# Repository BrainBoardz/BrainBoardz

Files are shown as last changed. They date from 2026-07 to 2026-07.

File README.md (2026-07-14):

### 

## BRAINBOARDZ - PLUG and CODE! 

BZBOARDS

This is the official repository for the BrainBoardz BZBoard system. BZBoards are ESP32-S3 and RP2350B based video (DVI/VGA) and audio centric microcontroller computers. They support Arduino, CircuitPython, MicroPython, AnnexRDS and PlatformIO. Our mission is to empower designers to develop projects based on our advanced and powerful microcontroller architecture. The entire BrainBoardz system is fully documented abd open source. The PCB designs and schematics for all BrainBoardz hardware is released under the CERN-OHL-W V2 license. All software and firmware is released under the GNU GPLv3 License. 

Through the use of our expanding range of cross compatible modules and easy prototyping boards anyone can easily develop custom projects to harness the impressive capabilities of the Raspberry Pi RP2350B and the Espressif ESP32-S3. The boards are specifically designed to be easily adaptable to retro-PC projects. Simply connect one of our ESP32-S3 or RP235OB boards to a USB cable and you are ready to go. 

BZBOARDS

We do not permit 3rd party board developers to use our logo/branding (as per CERN-OHL-W V2), but you are welcome to indicate that your project is BrainBoardz compatible if it is 100% (pin) compatible and it is produced using lead free solder.  The PCB designs and schematics for all BrainBoardz hardware is released under the CERN-OHL-W V2 license. All software and firmware is released under the GNU GPLv3 License. 

***

Firmware Notes: 

The ESP32S3 Zushi board supports Arduino and AnnexRDS. The RP2350B Beanz board supports CircuitPython, Micropython, Arduino and PlaformIO. For further instructions on these platforms please visit the Downloads page of the BrainBoardz website at:

https://www.brainboardz.com/downloads/

Plug and Code! 

<!--
**BrainBoardz/BrainBoardz** is a ✨ _special_ ✨ repository because its `README.md` (this file) appears on your GitHub profile.

-->

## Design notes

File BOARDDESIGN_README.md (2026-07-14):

All BrainBoardz projects are developed in EasyEDA using the EasyEDA Standard Edition. You can download this editor from here: 

<https://easyeda.com/page/download>

The schematics use parts that are sourced primarilly from LCSC. As some components are added post board production please check the BOM carefully!!!

**To utilize the project in EasyEDA use File:**

1) Open and select the zip file. EasyEDA will import the json files. 
1) Simply make a project using these files and you are good to go. 
1) We recommend starting with the Nucleus as the base project. This will ensure compatibility with the mounting holes of the Neuron modules (Z and M). 

**Usage Notes:** 

You are welcome to design/manufacture your own BrainBoardz boards. We do not allow 3rd party boards and modules to use our logo/branding, but you are welcome to indicate “BrainBoardz Compatible” on your board if it is 100% compatible and it is manufactured using a lead free process.

Please ensure that you follow the design guidelines closely. The pin assignments are very specific and have to be 100% consistent to maintain module compatibility.  The distances between the dupont connectors must be very precise. 

The schematics for all BZBOARDS and BZMODS/BZCARDS are being released under the Creative Commons Attribution Share-Alike License Version 4.0.  All code and firmware for BrainBoardz boards are being released under the GPL V3 License.

` `If you design a really interesting BZBoard or BZModule we would love to see it!

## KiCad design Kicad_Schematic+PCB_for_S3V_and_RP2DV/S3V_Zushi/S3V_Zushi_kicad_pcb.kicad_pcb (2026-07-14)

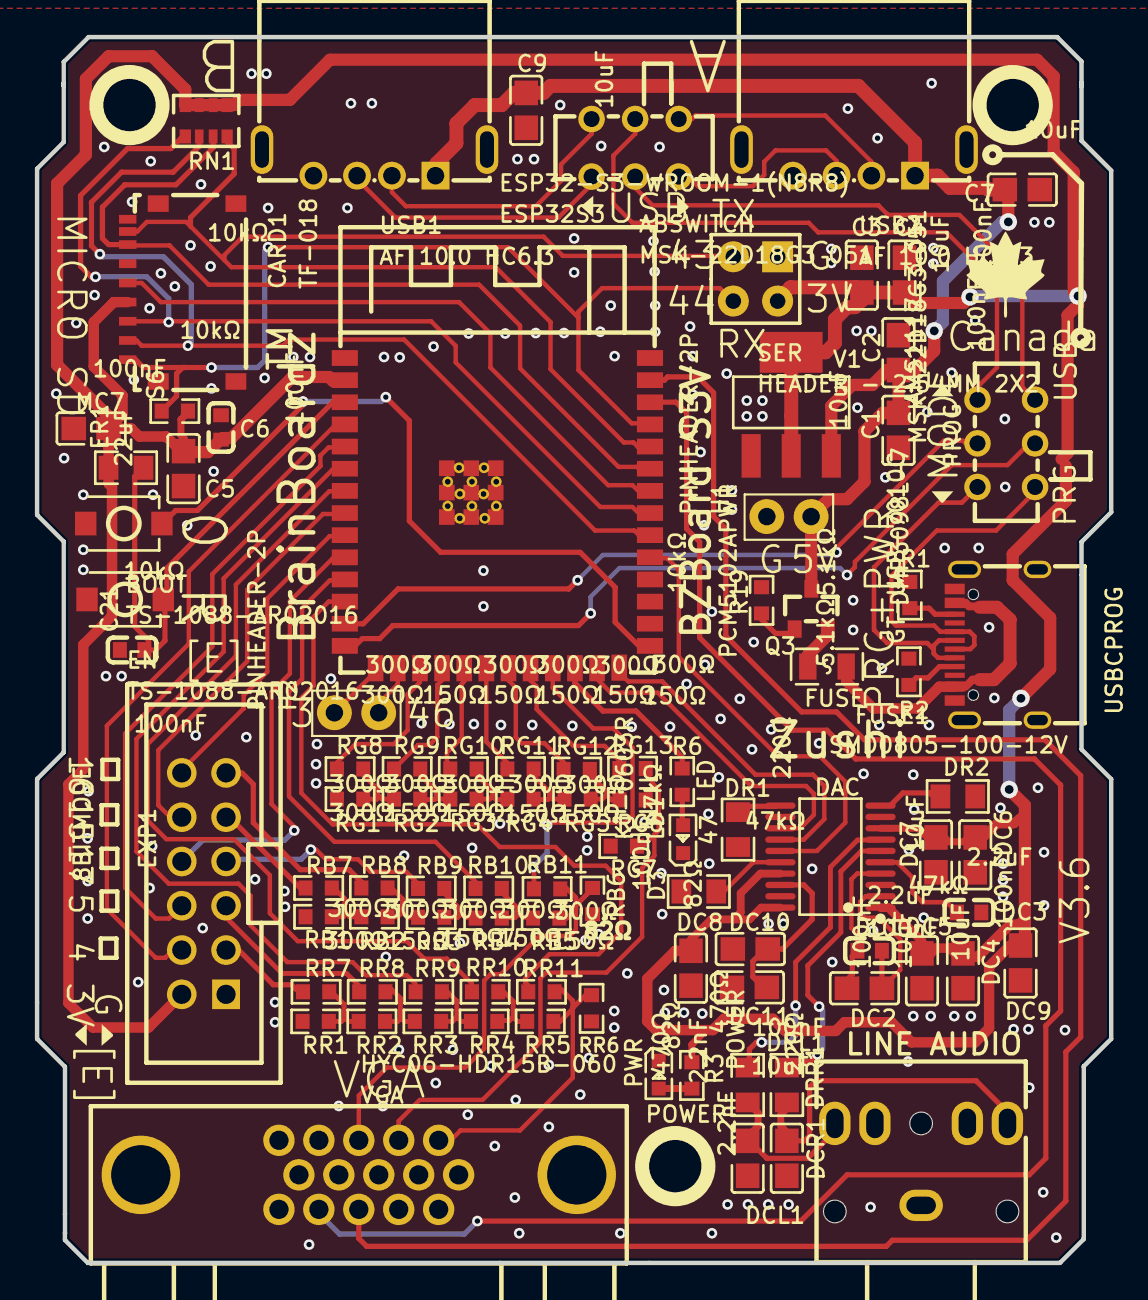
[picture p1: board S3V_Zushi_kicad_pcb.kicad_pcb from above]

Board: 2 copper layers, 61.6 x 70.3 mm, 107 parts (0 on the bottom side), 84 nets.

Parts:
ABSWITCH: MSK-22D18G3 051; SW-TH_HX-MSK-22D18G3-051
AUS: PJ-3062-G; AUDIO-TH_PJ-3062-G
BOOT: TS-1088-AR02016; SW-SMD_L3.9-W3.0-P4.45
C1, C3, C7, C9: 10uF; C0805
C2, C4: 100nF; C0805
C5: 22uF; C0805
C6, C21: 100nF; C0603
CARD1: TF-018; TF-SMD_TF-018
D3: 47kΩ; R0805
DAC: PCM5102APWR; TSSOP-20_L6.5-W4.4-P0.65-LS6.4-BL
DC1, DC3: 2.2uF; C0603
DC2, DC5, DC7, DC8, DC10: 100nF; C0805
DC4, DC6, DC9, DC11: 10uF; C0805
DCL1: 2.2nF; C0805
DCR1: 2.2nF; C0805
DR1, DR2: 47kΩ; R0805
DRL1: 470Ω; R0805
DRR1: 470Ω; R0805
EN: TS-1088-AR02016; SW-SMD_L3.9-W3.0-P4.45
ER1: 10kΩ; R0805
ESP32S3: ESP32-S3-WROOM-1(N8R8); WIRELM-SMD_ESP32-S3-WROOM-1
EXP1: 8BITMODE; IDC-TH_12P-P2.54_BOOMELE-2X6P-2.54MM
FUSE1: SMD0805-100-12V; F0805
H1, H2: PINHEADER-2P; CONNECTOR_PINHEADER_2.54MM{colon}PINHEADER_1X11_P_2.54MM
Hole_gge1593659: Hole_gge1593659
Hole_gge2213095: Hole_gge2213095
Hole_gge3207251: Hole_gge3207251
LD1: KT-0603R; LED0603-RD
MC7: 100nF; C0805
PROG: MSK-22D18G3 051; SW-TH_HX-MSK-22D18G3-051
PWR: POWER; LED0603-RD
Pad_gge1239083: Pad_gge1239083
Pad_gge1239086: Pad_gge1239086
Pad_gge1239089: Pad_gge1239089
Pad_gge1239092: Pad_gge1239092
Pad_gge1239095: Pad_gge1239095
Pad_gge1239098: Pad_gge1239098
Pad_gge1239101: Pad_gge1239101
Pad_gge1239104: Pad_gge1239104
Pad_gge1239107: Pad_gge1239107
Pad_gge1239110: Pad_gge1239110
Pad_gge1239113: Pad_gge1239113
Pad_gge1239116: Pad_gge1239116
Q3: DMP3098L-7; SOT-23_L2.9-W1.3-P1.90-LS2.4-BR
R1, R2: 5.1kΩ; R0603
R3, R6: 220Ω; R0603
R19: 10kΩ; R0603
RB1, RB7, RB8, RB9, RB10, RB11: 300Ω; R0603
RB2, RB3, RB4, RB5: 150Ω; R0603
RB6: 82Ω; R0603
RG1, RG8, RG9, RG10, RG11, RG12, RG13: 300Ω; R0603
RG2, RG3, RG4, RG5, RG6: 150Ω; R0603
RG7: 82Ω; R0603
RN1: 10kΩ; RES-ARRAY-SMD_0603-8P-L3.2-W1.6-BL
RR1, RR7, RR8, RR9, RR10, RR11: 300Ω; R0603
RR2, RR3, RR4, RR5: 150Ω; R0603
RR6: 82Ω; R0603
S6: 10kΩ; R0603
SER: HEADER - 2.54MM 2X2; 2X2X2.54MM HEADER
USB1, USB2: AF 10.0 HC6.3; USB-A-TH_AF-10.0-HC6.3
USBCPROG: GT-USB-7010C; USB-C-SMD_GT-USB-7010C
V1: AMS1117-3.3; SOT-223-3_L6.5-W3.4-P2.30-LS7.0-BR
VGA: HYC06-HDR15B-060; DSUB-TH_HYC06-HDR15B-060

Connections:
3.3V: C3.2, C4.2, C5.2, C6.2, CARD1.4, DAC.1, DAC.8, DAC.17, DAC.20, DC4.2, DC5.2, DC6.2, DC7.1, DC8.2, DC9.2, ER1.2, ESP32S3.2, EXP1.2, MC7.2, R3.1, RN1.1, RN1.2, RN1.3, RN1.4, S6.2, SER.3, V1.2, V1.4
+5V: C1.2, C2.2, C7.1, C9.1, H1.2, Q3.3, USB1.1, USB2.1, V1.3
AD+: ABSWITCH.1, USB2.3
AD-: ABSWITCH.4, USB2.2
BD+: ABSWITCH.3, USB1.3
BD-: ABSWITCH.6, USB1.2
BLUE: RB5.2, RB6.1, RB11.2, VGA.3
BOOT: BOOT.1, ESP32S3.27
D1+: PROG.4, USBCPROG.A6, USBCPROG.B6
D1-: PROG.1, USBCPROG.A7, USBCPROG.B7
D3_2: D3.2, DAC.16
DC2_1: DAC.4, DC1.1, DC2.1
DC2_2: DAC.2, DC1.2, DC2.2
DC3_1: DAC.5, DC3.1
DC10_1: DAC.18, DC10.1, DC11.1
DR1_2: DAC.11, DR1.2
DR2_2: DAC.10, DR2.2
EN: C21.1, EN.1, ER1.1, ESP32S3.3
G3: ESP32S3.15, H2.1
G4: ESP32S3.4, EXP1.4
G4VGA: EXP1.3, RR7.1
G5: ESP32S3.5, EXP1.6
G5VGA: EXP1.5, RR8.1
G6: ESP32S3.6, RR9.1
G7: ESP32S3.7, RR10.1
G8: ESP32S3.12, RR11.1
G9: ESP32S3.17, RG8.1
G10: ESP32S3.18, RG9.1
G11: ESP32S3.19, RG10.1
G12: ESP32S3.20, RG11.1
G13: ESP32S3.21, RG12.1
G14: ESP32S3.22, RG13.1
G15: ESP32S3.8, EXP1.10
G15VGA: EXP1.9, RB7.1
G16: ESP32S3.9, EXP1.12
G16VGA: EXP1.11, RB8.1
G17: ESP32S3.10, EXP1.8
G17VGA: EXP1.7, RB9.1
G18: ESP32S3.11, RB10.1
G19: ESP32S3.13, PROG.2
G20: ESP32S3.14, PROG.5
G21: ESP32S3.23, RB11.1
G38: DAC.15, ESP32S3.31
G39: CARD1.2, ESP32S3.32, RN1.6
G40: CARD1.3, ESP32S3.33, RN1.5
G41: CARD1.5, ESP32S3.34
G42: CARD1.7, ESP32S3.35, RN1.7
G43: CARD1.8, ESP32S3.36, RN1.8, SER.2
G44: CARD1.1, ESP32S3.37, S6.1, SER.4
G45: DAC.14, ESP32S3.26
G46: ESP32S3.16, H2.2
G47: ESP32S3.24, R6.1
G48: DAC.13, ESP32S3.25
GND: AUS.1, BOOT.2, C1.1, C2.1, C3.1, C4.1, C5.1, C6.1, C7.2, C9.2, C21.2, CARD1.6, CARD1.10, DAC.3, DAC.9, DAC.12, DAC.19, DC3.2, DC4.1, DC5.1, DC6.1, DC7.2, DC8.1, DC9.1, DC10.2, DC11.2, DCL1.1, DCR1.1, DR1.1, DR2.1, EN.2, ESP32S3.1, ESP32S3.40, ESP32S3.41, EXP1.1, H1.1, LD1.1, MC7.1, PWR.1, Pad_gge1239083.43, Pad_gge1239086.43, Pad_gge1239089.43, Pad_gge1239092.43, Pad_gge1239095.43, Pad_gge1239098.43, Pad_gge1239101.43, Pad_gge1239104.43, Pad_gge1239107.43, Pad_gge1239110.43, Pad_gge1239113.43, Pad_gge1239116.43, R1.2, R2.2, R19.2, RB1.1, RB6.2, RG1.1, RG7.2, RR1.1, RR6.2, SER.1, USB1.4, USB1.5, USB1.6, USB2.4, USB2.5, USB2.6, USBCPROG.1, USBCPROG.2, USBCPROG.3, USBCPROG.4, USBCPROG.A1B12, USBCPROG.B1A12, V1.1, VGA.5, VGA.6, VGA.7, VGA.8, VGA.10, VGA.16, VGA.17
GREEN: RG6.2, RG7.1, RG13.2, VGA.2
HSYNC: ESP32S3.39, VGA.13
OUTL: AUS.2, DCL1.2, DRL1.1
OUTLS: DAC.6, DRL1.2
OUTR: AUS.5, DCR1.2, DRR1.1
OUTRS: DAC.7, DRR1.2
Q3_1: Q3.1, R19.1
R3_2: PWR.2, R3.2
R6_2: LD1.2, R6.2
RB1_2: RB1.2, RB2.1, RB7.2
RB2_2: RB2.2, RB3.1, RB8.2
RB3_2: RB3.2, RB4.1, RB9.2
RB4_2: RB4.2, RB5.1, RB10.2
RED: RR5.2, RR6.1, RR11.2, VGA.1
RG1_2: RG1.2, RG2.1, RG8.2
RG2_2: RG2.2, RG3.1, RG9.2
RG3_2: RG3.2, RG4.1, RG10.2
RG4_2: RG4.2, RG5.1, RG11.2
RG5_2: RG5.2, RG6.1, RG12.2
RR1_2: RR1.2, RR2.1, RR7.2
RR8_2: RR2.2, RR3.1, RR8.2
RR9_2: RR3.2, RR4.1, RR9.2
RR10_2: RR4.2, RR5.1, RR10.2
UD+: ABSWITCH.2, PROG.6
UD-: ABSWITCH.5, PROG.3
USBCPROG_A5: R2.1, USBCPROG.A5
USBCPROG_B5: R1.1, USBCPROG.B5
VSYNC: ESP32S3.38, VGA.14
VUSB: FUSE1.1, USBCPROG.A4B9, USBCPROG.B4A9
VUSBPF: FUSE1.2, Q3.2

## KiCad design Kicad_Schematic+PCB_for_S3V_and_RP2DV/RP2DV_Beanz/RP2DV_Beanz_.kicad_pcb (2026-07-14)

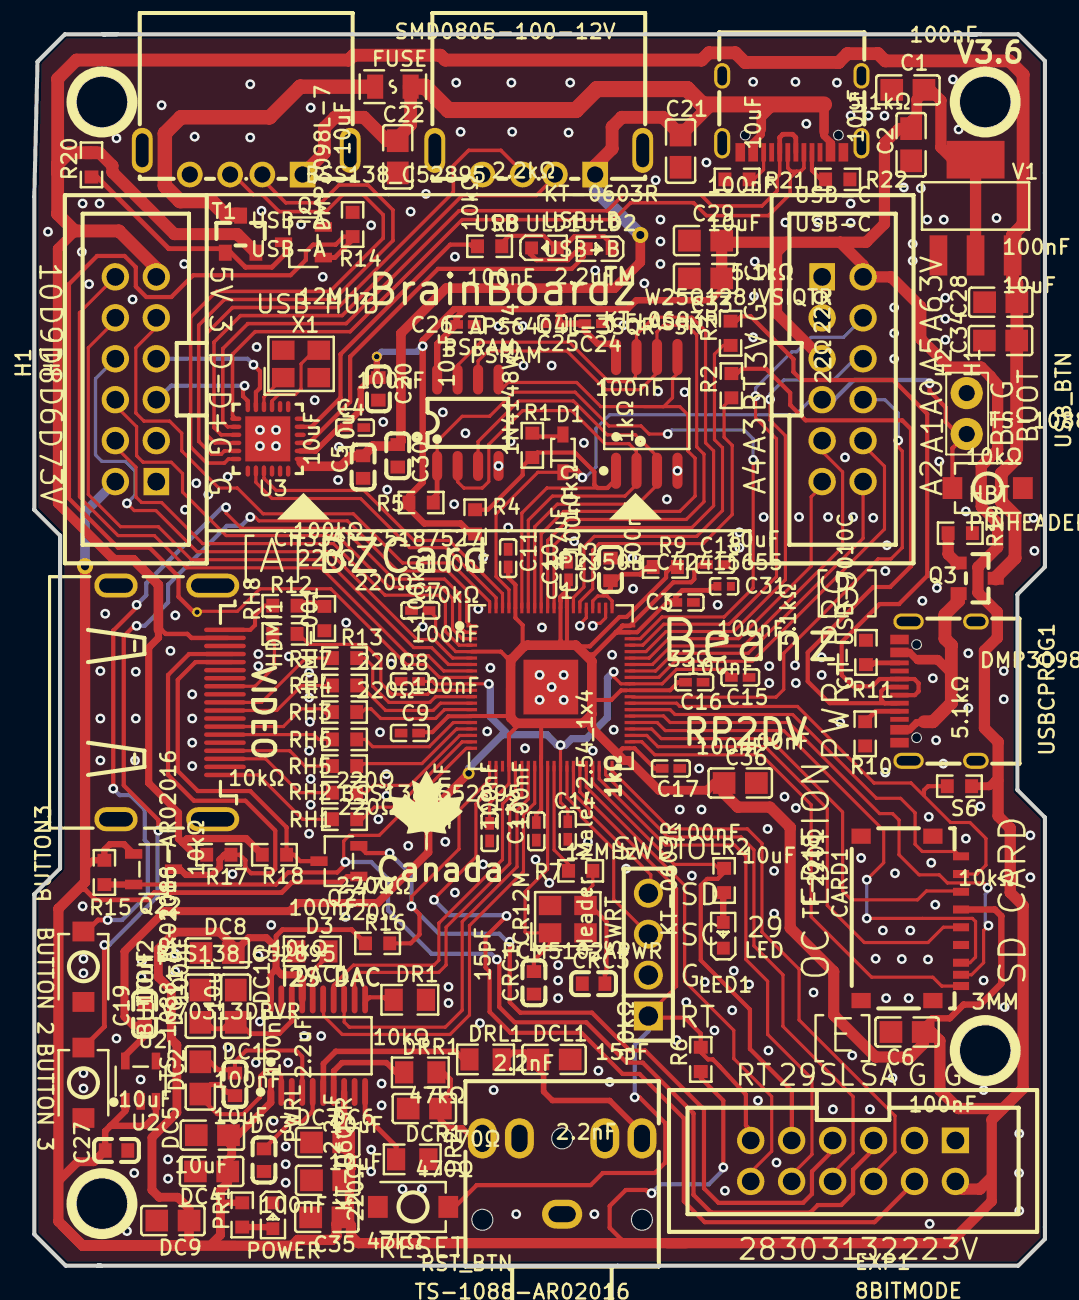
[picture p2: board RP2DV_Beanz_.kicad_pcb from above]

Board: 2 copper layers, 62.7 x 76.4 mm, 133 parts (0 on the bottom side), 116 nets.

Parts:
AUS1: PJ-3062-G; AUDIO-TH_PJ-3062-G
BUTTON2, BUTTON3: TS-1088-AR02016; SW-SMD_L3.9-W3.0-P4.45
C1, C6, C29, C34: 100nF; C0805
C2, C21, C22, C28, C33, C35, C36: 10uF; C0805
C3, C4, C7, C8, C9, C10, C11, C12, C13, C14, C15, C16, C17, C18, C24, C26: 100nF; C0402
C5, C19, C20, C27, C30: 10uF; C0603
C23: 4.7uF; C0603
C25: 2.2uF; C0402
C31: 10uF; C0402
CARD1: TF-018; TF-SMD_TF-018
CR12M: 12MHz; CRYSTAL-SMD_4P-L3.2-W2.5-BL
CRC1, CRC3: 15pF; C0603
D1: 1N4148WS T4; SOD-323_L1.8-W1.3-LS2.5-RD
D3: 47kΩ; R0805
DAC1: PCM5102APWR; TSSOP-20_L6.5-W4.4-P0.65-LS6.4-BL
DC1, DC3: 2.2uF; C0603
DC2, DC5, DC7, DC8, DC10: 100nF; C0805
DC4, DC6, DC9, DC11: 10uF; C0805
DCL1: 2.2nF; C0805
DCR1: 2.2nF; C0805
DR1, DR2: 47kΩ; R0805
DRL1: 470Ω; R0805
DRR1: 470Ω; R0805
EXP1: 8BITMODE; IDC-TH_12P-P2.54_BOOMELE-2X6P-2.54MM
FLASH: W25Q128JVSIQTR; SOIC-8_L5.3-W5.3-P1.27-LS8.0-BL
FUSE: SMD0805-100-12V; F0805
H1, H2: H1; IDC-TH_12P-P2.54_BOOMELE-2X6P-2.54MM
HBT: PINHEADER-2P; CONNECTOR_PINHEADER_2.54MM{colon}PINHEADER_1X11_P_2.54MM
HDMI1: HDMI-001; HDMI-SMD_19P-P0.50-H-F
Hole_gge3727755: Hole_gge3727755
Hole_gge3727770: Hole_gge3727770
Hole_gge3727785: Hole_gge3727785
Hole_gge3727818: Hole_gge3727818
LED1: KT-0603R; LED0603-RD
LR2: 220Ω; R0603
PR1: 220Ω; R0603
PSRAM: APS6404L-3SQR-SN; SOP-8_L4.9-W3.9-P1.27-LS6.0-BL
PWRL: KT-0603R; LED0603-RD
Pad_gge2986524: Pad_gge2986524
Pad_gge3015517: Pad_gge3015517
Pad_gge3860084: Pad_gge3860084
Pad_gge3861164: Pad_gge3861164
Pad_gge4051184: Pad_gge4051184
Q1, Q21, Q22: BSS138_C52895; SOT-23-3_L2.9-W1.6-P1.90-LS2.8-BR
Q3: DMP3098L-7; SOT-23_L2.9-W1.3-P1.90-LS2.4-BR
R1, R7: 1kΩ; R0603
R2, R3: 22Ω; R0603
R4, R5, R6, R14, R15, R16, R17, R18, R19, R20: 10kΩ; R0603
R8: 2.2kΩ; R0603
R9: 33Ω; R0603
R10, R11, R21, R22: 5.1kΩ; R0603
R12, R13: 100kΩ; R0603
RH1, RH2, RH3, RH4, RH5, RH6, RH7, RH8: 220Ω; R0603
RST_BTN: TS-1088-AR02016; SW-SMD_L3.9-W3.0-P4.45
S6: 10kΩ; R0603
SWRT: Header-Male-2.54_1x4; DIP-1X4P-2.54MM-M
T1: DMP3098L-7; SOT-23_L2.9-W1.3-P1.90-LS2.4-BR
U1: RP2350B_C42415655; QFN-80_L10.0-W10.0-P0.40-TL-EP3.4
U2: TLV70313DBVR; SOT-23-5_L3.0-W1.6-P0.95-LS2.8-BR
U3: CH334F_C5187527; QFN-24_L4.0-W4.0-P0.50-BL-EP2.8
ULD1, ULD2: KT-0603R; LED0603-RD
USB-A: USB-A; USB-A-TH_AF-10.0-HC6.3
USB-B: USB-B; USB-A-TH_AF-10.0-HC6.3
USB-C: USB-C; USB-C-SMD_GT-USB-7010C
USBCPROG1: GT-USB-7010C; USB-C-SMD_GT-USB-7010C
USB_BTN: TS-1088-AR02016; SW-SMD_L3.9-W3.0-P4.45
V1: AMS1117-3.3; SOT-223-3_L6.5-W3.4-P2.30-LS7.0-BR
X1: 12MHz; CRYSTAL-SMD_4P-L3.2-W2.5-BL

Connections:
1.3V: C8.2, C14.2, C15.2, C19.2, U1.10, U1.32, U1.51, U2.5
3.3V: C1.2, C2.2, C3.2, C4.1, C6.1, C7.2, C9.2, C10.2, C11.2, C12.2, C13.2, C16.2, C17.2, C18.2, C20.1, C24.2, C25.2, C26.1, C27.1, C29.2, C31.1, C33.2, C35.2, C36.2, CARD1.4, DAC1.1, DAC1.8, DAC1.17, DAC1.20, DC4.2, DC5.2, DC6.2, DC7.1, DC8.2, DC9.2, EXP1.2, FLASH.8, H1.2, H2.2, H2.5, PR1.1, PSRAM.8, Q21.1, Q22.1, R4.2, R5.2, R6.1, R9.1, R15.1, R16.2, S6.1, U1.5, U1.15, U1.24, U1.29, U1.41, U1.50, U1.59, U1.60, U1.68, U1.69, U1.76, U2.1, U2.3, U3.20, V1.2, V1.4
5V: C28.2, C34.2, H1.11, HDMI1.18, Q3.3, R17.1, R18.2, R20.2, T1.2, V1.3
A0: H2.8, U1.49
A1: H2.10, U1.52
A2: H2.12, U1.53
A3: H2.9, U1.54
A4: H2.11, U1.55
A5: H2.6, U1.56
A6: H2.4, U1.57
D6: H1.6, U1.3
D7: H1.4, U1.4
D8_TX1: H1.8, U1.6
D9_RX1: H1.10, U1.7
D10: H1.12, U1.8
D+: R2.2, U1.67
D+1: U3.12, USB-A.3
D+2: U3.10, USB-B.3
D+3: U3.8, USB-C.A6, USB-C.B6
D+4: H1.5, U3.6
D-: R3.2, U1.66
D-1: U3.11, USB-A.2
D-2: U3.9, USB-B.2
D-3: U3.7, USB-C.A7, USB-C.B7
D-4: H1.7, U3.5
DAC1_2: DAC1.2, DC1.2, DC2.2
DAC1_4: DAC1.4, DC1.1, DC2.1
DAC1_5: DAC1.5, DC3.1
DAC1_10: DAC1.10, DR2.2
DAC1_11: DAC1.11, DR1.2
DAC1_16: D3.2, DAC1.16
DC11_1: DAC1.18, DC10.1, DC11.1
GND: AUS1.1, BUTTON2.2, BUTTON3.2, C1.1, C2.1, C3.1, C4.2, C5.1, C6.2, C7.1, C8.1, C9.1, C10.1, C11.1, C12.1, C13.1, C14.1, C15.1, C16.1, C17.1, C18.1, C19.1, C20.2, C21.2, C22.1, C23.2, C24.1, C25.1, C26.2, C27.2, C28.1, C29.1, C30.1, C31.2, C33.1, C34.1, C35.1, C36.1, CARD1.6, CARD1.10, CR12M.2, CR12M.4, CRC1.1, CRC3.2, DAC1.3, DAC1.9, DAC1.19, DC3.2, DC4.1, DC5.1, DC6.1, DC7.2, DC8.1, DC9.1, DC10.2, DC11.2, DCL1.1, DCR1.1, DR1.1, DR2.1, EXP1.1, EXP1.3, FLASH.4, H1.1, H1.3, H2.1, H2.3, HBT.2, HDMI1.2, HDMI1.5, HDMI1.8, HDMI1.11, HDMI1.17, HDMI1.20, HDMI1.21, HDMI1.22, HDMI1.23, LED1.1, PSRAM.4, PWRL.1, Q1.2, R10.2, R11.2, R13.2, R14.1, R19.2, R21.2, R22.2, RST_BTN.2, SWRT.2, U1.62, U1.65, U1.81, U2.2, U3.25, USB-A.4, USB-A.5, USB-A.6, USB-B.4, USB-B.5, USB-B.6, USB-C.1, USB-C.2, USB-C.3, USB-C.4, USB-C.A1B12, USB-C.B1A12, USBCPROG1.1, USBCPROG1.2, USBCPROG1.3, USBCPROG1.4, USBCPROG1.A1B12, USBCPROG1.B1A12, USB_BTN.2, V1.1, X1.2, X1.4
GPIO3: H1.9, U1.80
GPIO4: BUTTON2.1, U1.1
GPIO5: BUTTON3.1, U1.2
GPIO22: EXP1.4, U1.22
GPIO28: EXP1.12, U1.36
GPIO30: EXP1.10, U1.38
GPIO31: EXP1.8, U1.39
GPIO32: EXP1.6, U1.40
HDMI1_1: HDMI1.1, RH1.2
HDMI1_3: HDMI1.3, RH2.2
HDMI1_4: HDMI1.4, RH5.1
HDMI1_6: HDMI1.6, RH6.1
HDMI1_7: HDMI1.7, RH3.2
HDMI1_9: HDMI1.9, RH4.2
HDMI1_10: HDMI1.10, RH7.1
HDMI1_12: HDMI1.12, RH8.1
HDMI1_19: HDMI1.19, R12.1
HDMI-SCL: HDMI1.15, Q21.3, R18.1
HDMI-SDA: HDMI1.16, Q22.3, R17.2
HOTPLUG_3V: R12.2, R13.1
HSTX12: RH8.2, U1.11
HSTX13: RH7.2, U1.12
HSTX14: RH4.1, U1.13
HSTX15: RH3.1, U1.14
HSTX16: RH6.2, U1.16
HSTX17: RH5.2, U1.17
HSTX18: RH2.1, U1.18
HSTX19: RH1.1, U1.19
I2S_BCLK: DAC1.13, U1.27
I2S_DIN: DAC1.14, U1.25
I2S_LRCLK: DAC1.15, U1.28
I2S_MCLK: DAC1.12, U1.26
LED: EXP1.9, LR2.1, U1.37
LED1_2: LED1.2, LR2.2
LED2: R8.1, U3.23
LED4: U3.21, ULD1.1, ULD2.2
MISO/SDIO_DAT0: CARD1.7, U1.45
MOSI/SDIO_CMD: CARD1.3, U1.44
OUTL: AUS1.2, DCL1.2, DRL1.1
OUTLS: DAC1.6, DRL1.2
OUTR: AUS1.5, DCR1.2, DRR1.1
OUTRS: DAC1.7, DRR1.2
PSRAM_CS: PSRAM.1, R5.1, U1.58
PWRL_2: PR1.2, PWRL.2
Q1_3: Q1.3, R20.1, T1.1
Q3_1: Q3.1, R19.1
QSPI_CS: FLASH.1, R1.2, R4.1, U1.75
QSPI_DATA[0]: FLASH.5, PSRAM.5, U1.72
QSPI_DATA[1]: FLASH.2, PSRAM.2, U1.74
QSPI_DATA[2]: FLASH.3, PSRAM.3, U1.73
QSPI_DATA[3]: FLASH.7, PSRAM.7, U1.70
QSPI_SCK: FLASH.6, PSRAM.6, U1.71
R1_1: D1.2, R1.1
R10_1: R10.1, USBCPROG1.A5
R11_1: R11.1, USBCPROG1.B5
RESET: EXP1.11, R6.2, RST_BTN.1, SWRT.1, U1.35
SCK/SDIO_CLK: CARD1.5, U1.43
SCL: EXP1.7, Q21.2, R16.1, U1.21
SDA: EXP1.5, Q22.2, R15.2, U1.20
SDCS/SDIO_DAT3: CARD1.2, S6.2, U1.48
SDIO_DAT1: CARD1.8, U1.46
SDIO_DAT2: CARD1.1, U1.47
SD_DETECT: CARD1.9, U1.42
SWCLK: SWRT.3, U1.33
SWDIO: SWRT.4, U1.34
T1_3: FUSE.1, T1.3
ULD2_1: R8.2, ULD1.2, ULD2.1
USB-C_A5: R22.1, USB-C.A5
USB-C_B5: R21.1, USB-C.B5
USBH-D+: U1.78, U3.15
USBH-D-: U1.79, U3.14
USBH_PWR: Q1.1, R14.2, U1.9
USB_BOOT: D1.1, H2.7, HBT.1, U1.77, USB_BTN.1
USB_D+: R2.1, USBCPROG1.A6, USBCPROG1.B6
USB_D-: R3.1, USBCPROG1.A7, USBCPROG1.B7
VBUS: C5.2, C21.1, C22.2, C30.2, FUSE.2, U3.19, USB-A.1, USB-B.1, USB-C.A4B9, USB-C.B4A9
VREG-AVDD: C23.1, R9.2, U1.61, U1.64
VUSB: Q3.2, USBCPROG1.A4B9, USBCPROG1.B4A9
XI: U3.4, X1.1
XIN: CR12M.1, CRC1.2, U1.30
XO: U3.3, X1.3
XOUT: CR12M.3, CRC3.1, R7.2
XOUTR: R7.1, U1.31

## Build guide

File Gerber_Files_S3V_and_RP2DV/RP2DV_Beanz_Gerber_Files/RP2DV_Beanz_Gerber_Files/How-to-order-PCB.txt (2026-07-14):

How to Order PCB

Please refer to:
https://docs.easyeda.com/en/PCB/Order-PCB
